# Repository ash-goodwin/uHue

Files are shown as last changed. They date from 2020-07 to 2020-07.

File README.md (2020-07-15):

# uHUE

*A USB-controlled LED light/indicator*

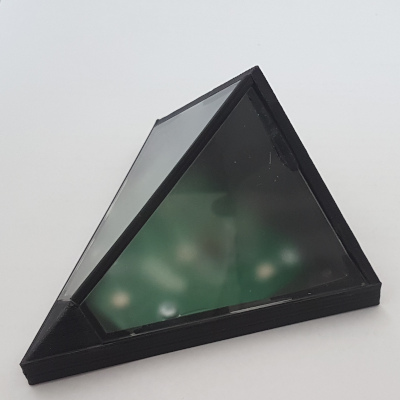
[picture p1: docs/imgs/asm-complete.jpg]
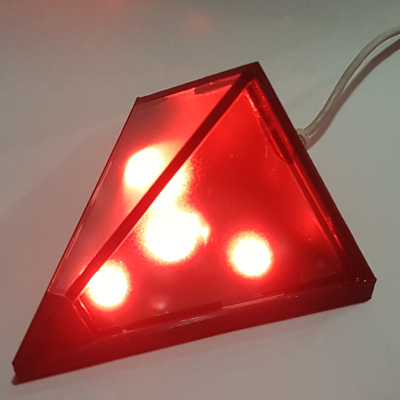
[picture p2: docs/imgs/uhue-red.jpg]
|  |  |
|--|--|

The uHUE is a simple USB-controlled light/indicator that arose from my need to add an externally visible status indicator to a PC-based test station I'd created. The idea was that it would allow the user to monitor the status of a test without having to be able to see the display. The uHUE interfaces with the PC using a USB-to-serial converter, whilst an on-board microcontroller controls the LEDs.

The colour shown by the uHUE is specified using three 8-bit values - one each for red, green and blue. Three 'patterns' are possible when showing a colour: solid, blink and fade. For blink and fade, the cycle time can also be controlled.

The housing is designed to allow the LED colour being shown to be viewed over a 180° horizontal arc and 90° vertical arc. For simplicity, I opted to use integrated magnets hold the uHUE in place rather than a more permanent fixing method.

For more information:
- [Circuit](docs/circuit.md)
- [Housing](docs/housing.md)
- [Protocol](docs/protocol.md)
- [Assembly](docs/assembly.md)

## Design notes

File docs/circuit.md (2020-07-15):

# Circuit

The uHUE uses four World Semi [WS2812B](datasheets/WS2812B.pdf) LEDs, controlled from a Microchip [PIC16F1704](datasheets/PIC16F1704.pdf). The PIC interfaces to the PC using a Silicon Labs [CP2104](datasheets/CP2104.pdf) USB-to-serial converter.

The WS2812B LEDs use a daisy-chained single-wire serial protocol to control the colour. It's a slightly odd protocol that uses different pulse widths to signify 1 and 0. Microchip have published an [application note](https://web.archive.org/web/20190417040127/http://ww1.microchip.com/downloads/en/AppNotes/00001606A.pdf) that explains how to use the Configurable Logic Cell (CLC) contained within some PICs to control the WS2812B. The app note is not written explicitly for the PIC16F1704 but is easily adapted.

I chose all components based on familiarity and the fact that I could have the PCBs assembled from in-stock items by JLCPCB. The only part I had to hand solder was the USB connector.

Below you can see the PCB as it came from JLCPCB, namely with all components except the USB connector.

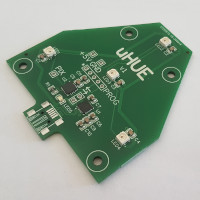
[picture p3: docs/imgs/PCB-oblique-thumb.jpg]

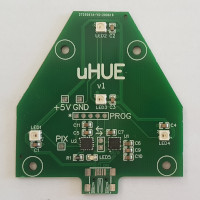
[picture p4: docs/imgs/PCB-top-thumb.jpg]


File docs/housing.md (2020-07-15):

# Housing

For my use case, the uHUE was going to be mounted to an overhead cable tray, with the LEDs projecting downwards. To allow the colour to be seen from side on, the housing uses two angled pieces of frosted acrylic to diffuse the light. This provides visibilty over a 180° horizontal arc and a 90° vertical arc. The frosted acrylic also makes the uHUE "glow" as a whole, rather than four point sources of light. The unit is held in place using three integrated magnets that are glued into the base, used to anchor the uHUE to a metal cable tray.

The housing is made of four parts, three of which can be 3D printed using FDM: the base, the frame and the spine. The fourth part is the laser-cut frosted acrylic "window". Two pieces of the acrylic are required per unit.

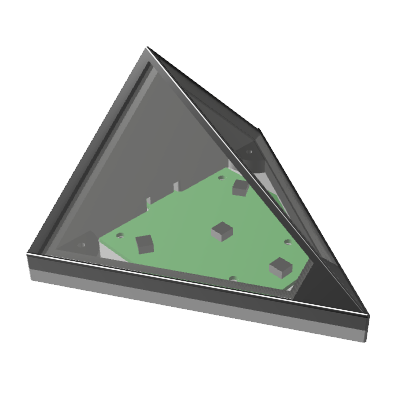
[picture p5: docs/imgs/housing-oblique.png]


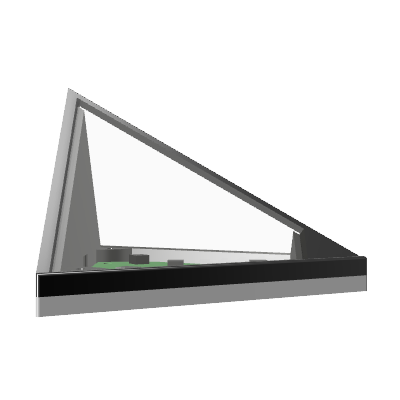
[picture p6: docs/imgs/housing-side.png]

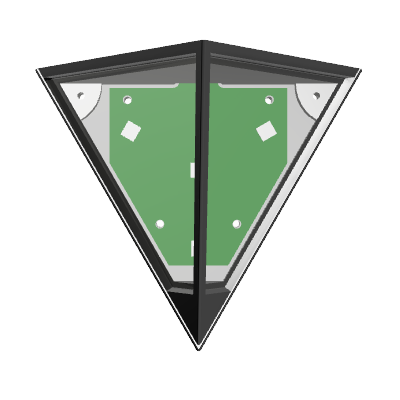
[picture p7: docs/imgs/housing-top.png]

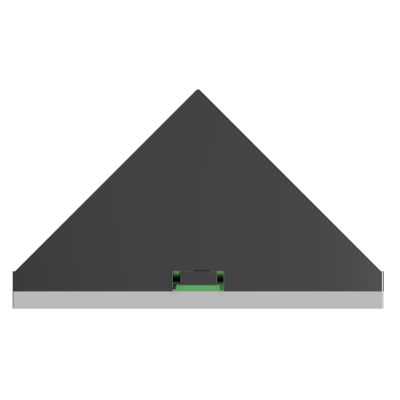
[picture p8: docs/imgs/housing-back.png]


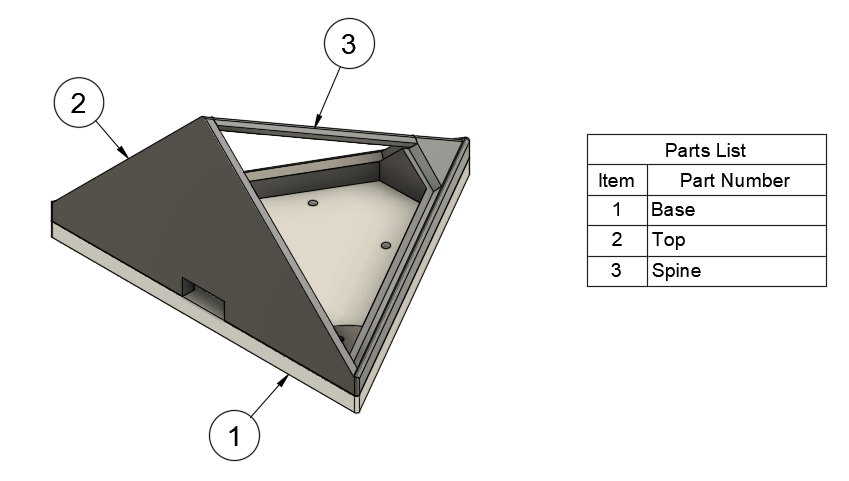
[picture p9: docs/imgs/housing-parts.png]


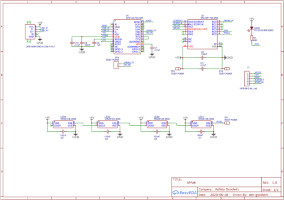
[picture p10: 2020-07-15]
docs/imgs/Schematic-thumb.jpg

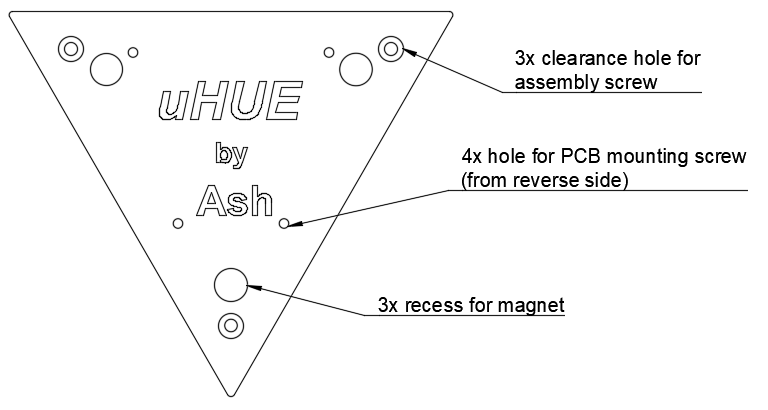
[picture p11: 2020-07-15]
docs/imgs/housing-base-detail.png

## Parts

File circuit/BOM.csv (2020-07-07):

ID | Name | Designator | Footprint | Quantity | Manufacturer Part | Manufacturer | Supplier | Supplier Part | LCSC Assembly
1 | 680 | R1 | R0805 | 1 | 0805W8F6800T5E | UniOhm | LCSC | C17798 | Yes
2 | 100nF | C9,C1,C2,C3,C4,C5 | C0805 | 6 | CC0805KRX7R9BB104 | YAGEO | LCSC | C49678 | Yes
3 | CP2104-F03-GM | U1 | QFN-24_L4.0-W4.0-P0.50-BL-EP2.8 | 1 | CP2104-F03-GM | SILICON LABS | LCSC | C47742 | Yes
4 | FC-2012HRK-620D | LED5 | LED0805-RD | 1 | FC-2012HRK-620D | NATIONSTAR | LCSC | C84256 | Yes
5 | WS2812B-3535 | LED4,LED3,LED1,LED2 | LED-SMD_4P-L3.5-W3.5-TL_WS2812B | 4 | WS2812B-3535 | Worldsemi | LCSC | C114583 | Yes
6 | TEST POINT | TP1,TP2,TP3 | HDR-M-2.54_1X1 | 3 |  |  | LCSC | C81276
7 | PIC16F1704-I/ML | U2 | QFN-16_L4.0-W4.0-P0.65-BL-EP2.6 | 1 | PIC16F1704-I/ML | MICROCHIP | LCSC | C145568 | Yes
8 | TEST POINT | TP4 | HDR-M-2.54_1X2 | 1 |  |  | LCSC | C124375
9 | HDR-M-2.54_1x5 | J1 | HDR-M-2.54_1X5 | 1
10 | 4.7uF | C7,C10,C11 | C0805 | 3 | CL21A475KAQNNNE | SAMSUNG | LCSC | C1779 | Yes
11 | USB-MINI-SMD-9.2X9.4-H3.7 | USB1 | MINI-USB-SMD_C105424 | 1 | USB-MINI-SMD-9.2X9.4-H3.7 | LCSC | LCSC | C105424
12 | 1uF | C6 | C0805 | 1 | CL21B105KBFNNNE | SAMSUNG | LCSC | C28323 | Yes

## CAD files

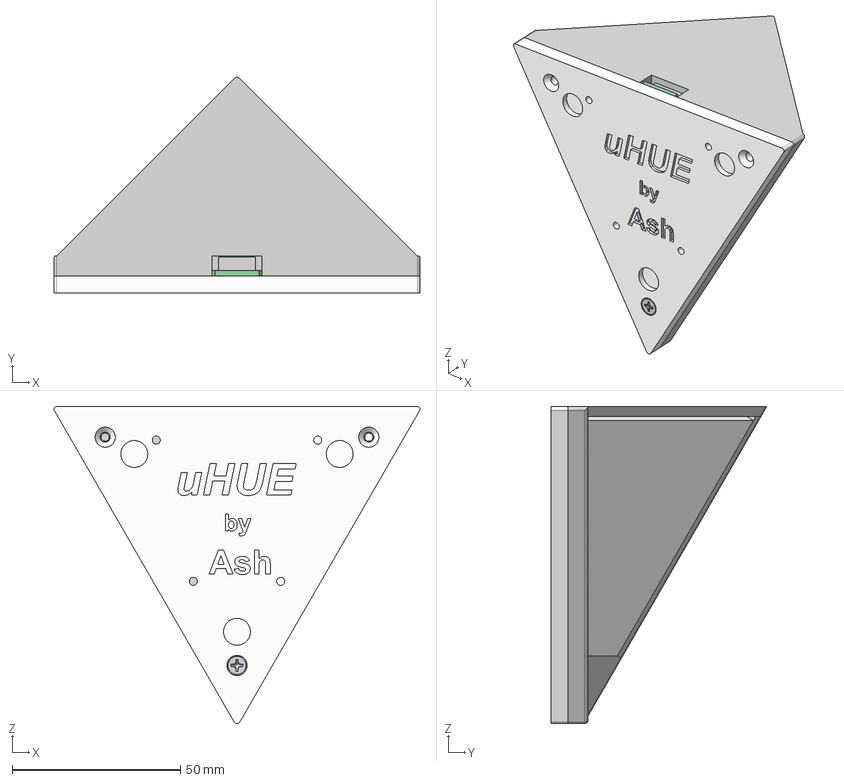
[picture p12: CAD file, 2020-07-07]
housing/assembly v10.iges
108.8 x 64.1 x 94.3 mm

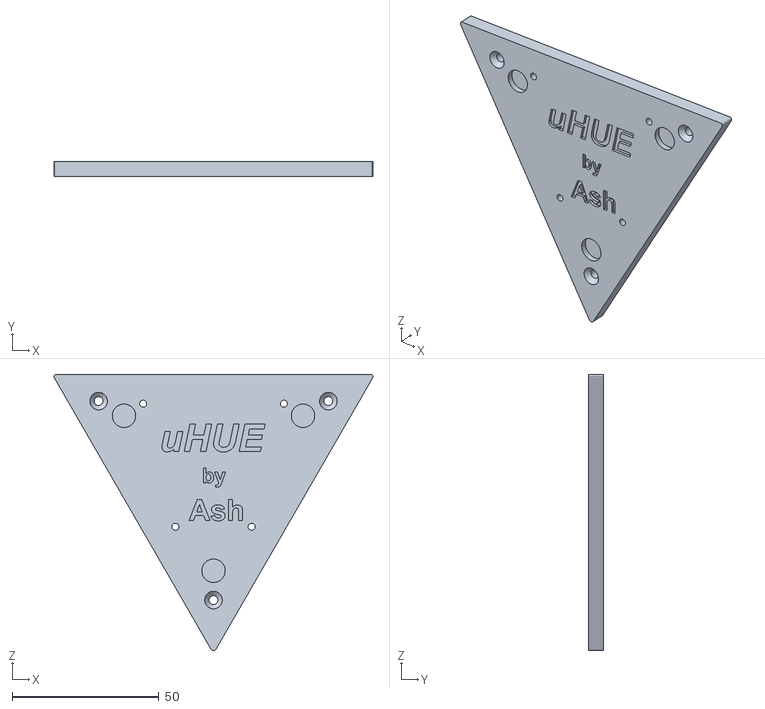
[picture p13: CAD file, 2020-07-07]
housing/Base.stl
108.8 x 5.00 x 94.3

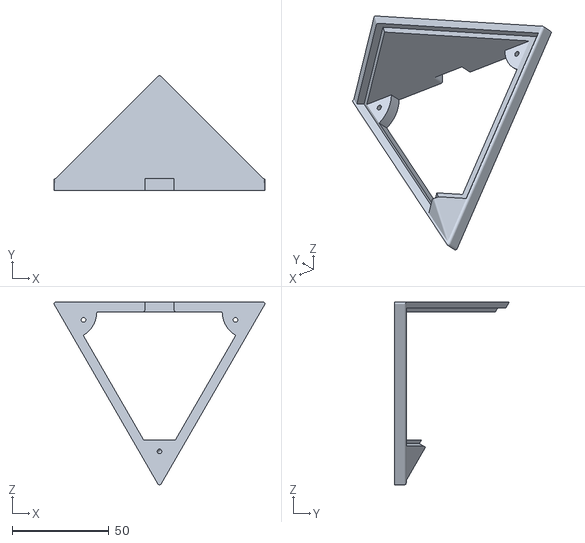
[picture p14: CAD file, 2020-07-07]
housing/Top.stl
108.8 x 59.1 x 94.3

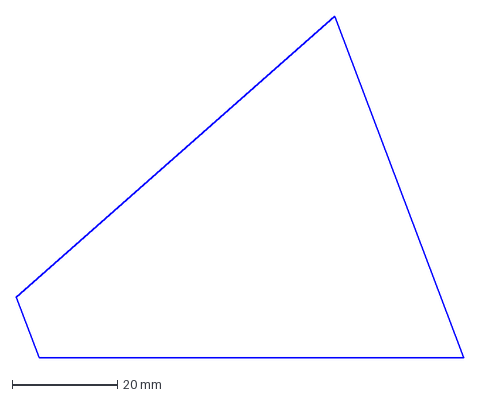
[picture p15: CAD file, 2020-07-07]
housing/pane.dxf
85.2 x 65.0 mm

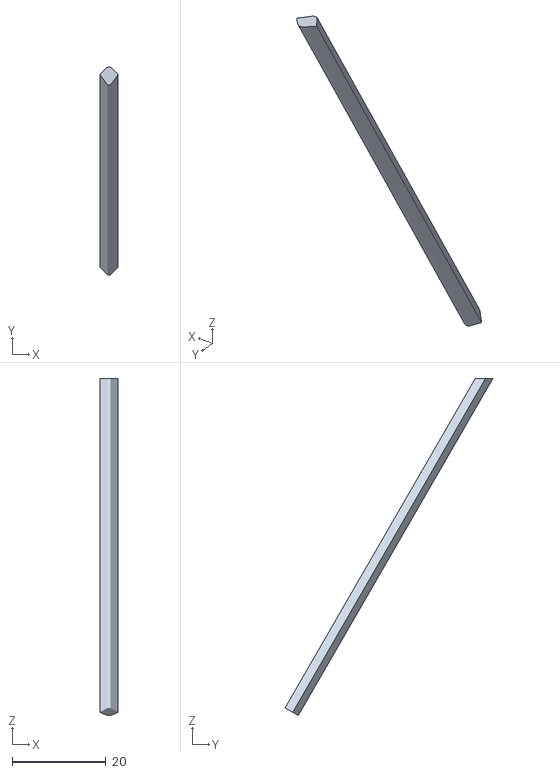
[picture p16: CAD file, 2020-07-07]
housing/Spine.stl
3.93 x 44.3 x 71.8

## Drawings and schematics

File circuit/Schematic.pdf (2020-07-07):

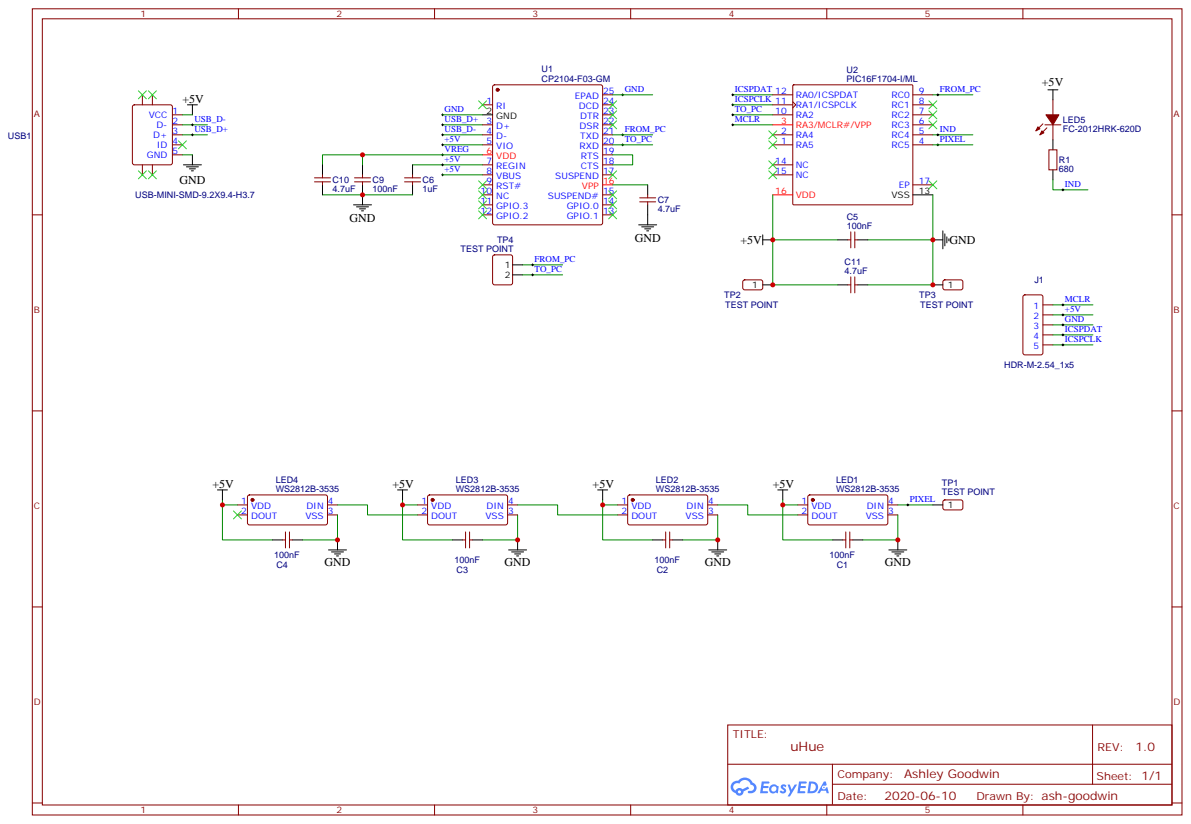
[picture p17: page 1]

Drawn By: ash-goodwin

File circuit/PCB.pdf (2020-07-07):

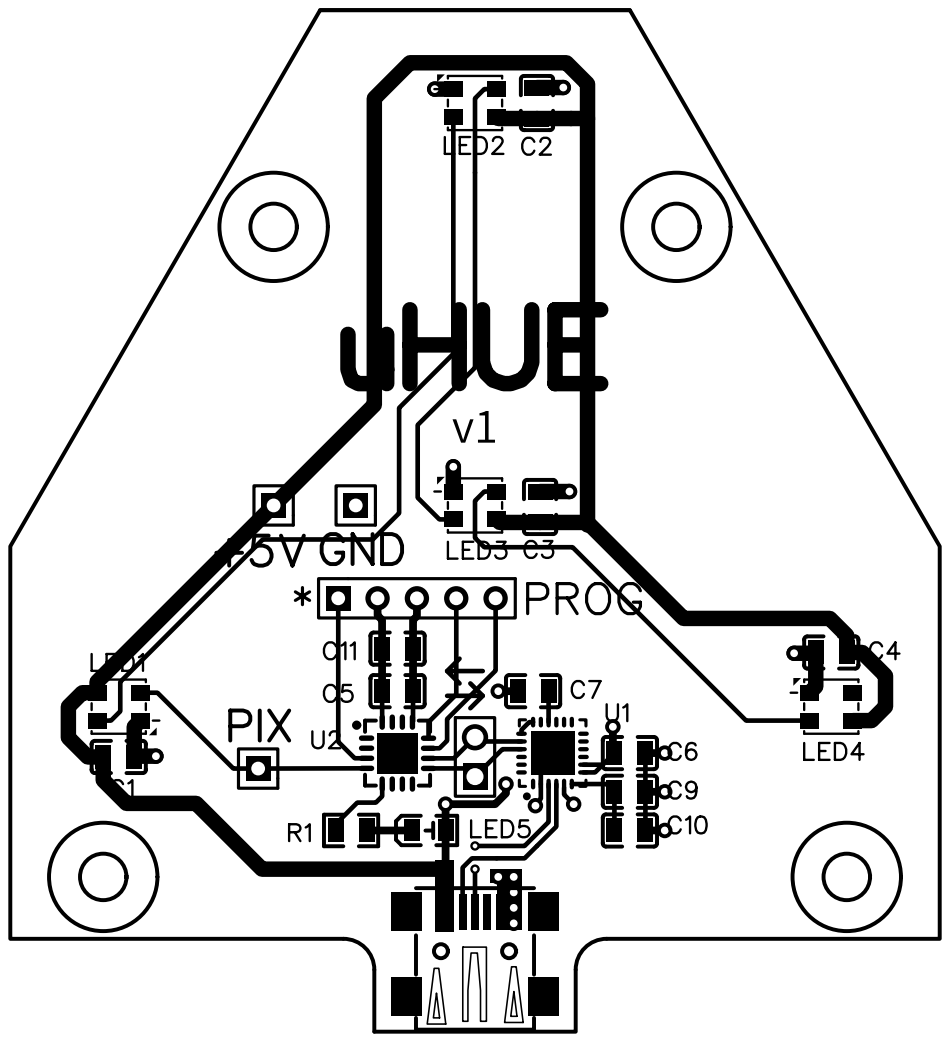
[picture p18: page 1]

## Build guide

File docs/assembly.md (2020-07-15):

# Assembly

Assembly of the uHUE is pretty straightforward.

Finishing the PCB:
1. Solder on the USB connector (if using JLCPCB SMT assembly service).
2. Program the PIC microcontroller. I have access to a 'REAL ICE' programmer, but any PIC-compatible programmer will work.
3. Test the uHUE using the [Tester software](../software) to make sure everything is working properly.

Assemble the housing:
1. Glue two pieces of the frosted acrylic into the 'frame' part.
2. Glue the 'spine' to the frame and acrylic panes, again with epoxy.
3. Separately, glue the three magnets into the base.

I used epoxy that I applied with a toothpick to glue everything together.

Once the glue/epoxy has cured:
1. Secure the PCB onto the base using 4x screws.
2. Secure the base to the frame with 3x screws.

| _Frame with 'windows' and spine glued into place_ |
|:--:|
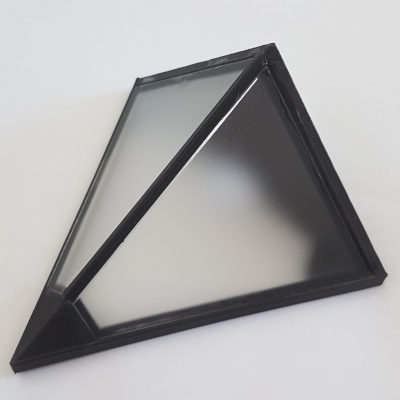
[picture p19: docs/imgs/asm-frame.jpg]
|  |

| _Base with magnet glued into place_ |
|:--:|
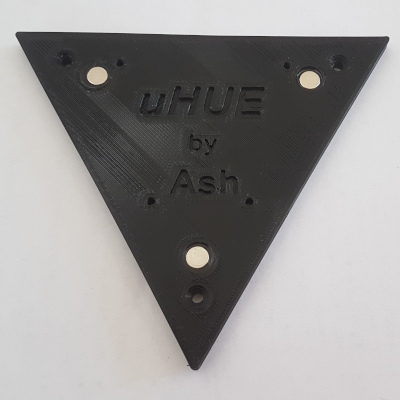
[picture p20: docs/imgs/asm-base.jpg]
|  |

| _PCB attached to base_ |
|:--:|
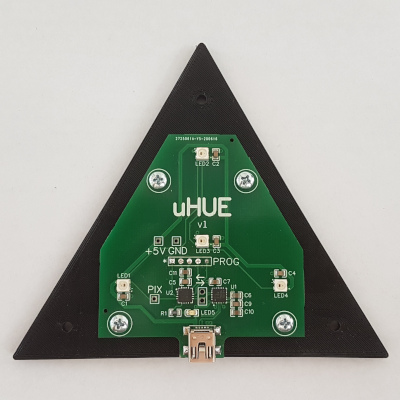
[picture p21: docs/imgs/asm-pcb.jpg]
|  |

| _Completed assembly_ |
|:--:|
|  |

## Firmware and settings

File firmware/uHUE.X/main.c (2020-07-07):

#include "main.h"
#include "led.h"
#include "mcc_generated_files/mcc.h"

#define FRAME_FLAG_START            0xFE
#define FRAME_FLAG_END              0xFF
#define FRAME_FLAG_ESCAPE           0xFD
#define FRAME_ESCAPE_XOR            0x20

#define ACTIVITY_LED_BLINK_COUNT    (10)

static struct {
    uint8_t buffer[10];
    int     count;
    
    uint8_t started : 1;
    uint8_t escapeNext : 1;
} receive;

static uint8_t activityLedCount = 0;

struct s_Timing timing;

void doReceive( void );
void processMessage( void );
void sendMessage( uint8_t *data, int length );
void blinkActivityLed( void );
void doActivityLed( void );

void main(void)
{
    // initialize the device
    SYSTEM_Initialize();

    Led_Initialise();
    
    // Lock PPS
    PPSLOCK = 0x55;
    PPSLOCK = 0xAA;
    PPSLOCKbits.PPSLOCKED = 1;
    
    // Enable the Global Interrupts
    INTERRUPT_GlobalInterruptEnable();

    // Enable the Peripheral Interrupts
    INTERRUPT_PeripheralInterruptEnable();

    while( true ) {
        doReceive();
        
        if( timing.tenMsTick ) {
            timing.tenMsTick = false;
            
            Led_Process();
            doActivityLed();
            
            CLRWDT();
        }
    }
}


void doReceive( void )
{
    while( EUSART_is_rx_ready() ) {
        uint8_t rx = EUSART_Read();
        
        blinkActivityLed();
                
        if( rx == FRAME_FLAG_START ) {
            receive.started = true;
            receive.count = 0;
            receive.escapeNext = false;
        }
        else if( rx == FRAME_FLAG_END ) {
            processMessage();
            receive.started = false;
        }
        else if( rx == FRAME_FLAG_ESCAPE ) {
            receive.escapeNext = true;
        }
        else if( receive.started ) {
            
            if( receive.count == sizeof( receive.buffer ) ){
                // Already filled buffer and next char wasn't the END flag.
                // :(
                receive.started = false;
                continue;
            }
            
            if( receive.escapeNext ) {
                rx ^= FRAME_ESCAPE_XOR;
                receive.escapeNext = false;
            }            
            
            receive.buffer[ receive.count++ ] = rx;            
        }
        
    }
}

void processMessage( void )
{
    uint8_t * data = receive.buffer;
    int dataLength = receive.count;
    struct s_LedColour colour = {
        .red = data[1],
        .green = data[2],
        .blue = data[3]
    };
    
    //sendMessage( data, dataLength );
    
    // Request for firmware version.
    // Format:  'v'
    if( dataLength == 1 && data[0] == 'v' ) {
        uint8_t version[] = "uHUE by Ash, v1";
        sendMessage( version, sizeof( version ) - 1 );
    }
    // Set solid colour.
    // Format:  'c', {red}, {green}, {blue}, {optional: cycle period, which is ignored}
    else if( dataLength >= 4 && data[0] == 'c' ) {
        Led_SetColour( PATTERN_SOLID, 0, colour );
    }
    // Set fading colour.
    // Format:  'f', {red}, {green}, {blue}, {cycle period in deci-seconds}
    else if( dataLength == 5 && data[0] == 'f' ) {
        Led_SetColour( PATTERN_FADE, data[4], colour );
    }
    // Set blinking colour.
    // Format:  'b', {red}, {green}, {blue}, {cycle period in deci-seconds}
    else if( dataLength == 5 && data[0] == 'b' ) {
        Led_SetColour( PATTERN_BLINK, data[4], colour );
    }    
}

void sendMessage( uint8_t *data, int length )
{
    EUSART_Write( FRAME_FLAG_START );
    
    while( length-- ) {
        if( *data >= FRAME_FLAG_ESCAPE ) {
            EUSART_Write( FRAME_FLAG_ESCAPE );
            EUSART_Write( *data ^ FRAME_ESCAPE_XOR );
        }
        else {
            EUSART_Write( *data );
        }
        data++;
    }
    
    EUSART_Write( FRAME_FLAG_END );
}

void blinkActivityLed( void )
{
    activityLedCount = ACTIVITY_LED_BLINK_COUNT;
    IO_LED_SetLow();    
}

void doActivityLed( void )
{
    if( activityLedCount ) {
        if( --activityLedCount == 0 ) {
            IO_LED_SetHigh();
        }
    }
}

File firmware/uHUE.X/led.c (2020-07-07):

#include "main.h"
#include "led.h"
#include "mcc_generated_files/mcc.h"

#define TICKS_PER_DECISECOND        (TICKS_PER_SECOND / 10)
#define NUM_LEDS                    (4)


static struct {
    struct {
        enum e_LedPattern   pattern;
        uint16_t            patternTime;
        struct s_LedColour  colour;
    } Setting;
        
    uint16_t                 cycleTimer;    
} led;

static const struct s_LedColour ColourOff = { 0, 0, 0 };

static void _WriteColour( struct s_LedColour colour );
static struct s_LedColour _MixColours( struct s_LedColour colourA, struct s_LedColour colourB, uint16_t dividend, uint16_t divisor );



void Led_Initialise( void )
{
    SPI_Open( SPI_DEFAULT );
    _WriteColour( ColourOff );
}
        
void Led_SetColour( enum e_LedPattern pattern, uint8_t patternTime, struct s_LedColour colour )
{
    led.Setting.pattern = pattern;
    led.Setting.patternTime = (uint16_t)patternTime * TICKS_PER_DECISECOND;
    led.Setting.colour = colour;    
    
    // Reset fade/blink timer
    led.cycleTimer = 0;
    
    switch( led.Setting.pattern ){
        case PATTERN_SOLID:
            // Just set the colour and done!
            _WriteColour( led.Setting.colour );
            break;

        case PATTERN_FADE:
            // Start with light off.
            _WriteColour( ColourOff );
            break;

        case PATTERN_BLINK:
            // Start with selected colour.
            _WriteColour( led.Setting.colour );
            break;
    } 
}


void Led_Process( void )
{       
    // Increase cycle timer.
    led.cycleTimer += 1;
    if( led.cycleTimer >= led.Setting.patternTime ) {
        led.cycleTimer = 0;
    }
    
    // Update light with new colour based on new position in cycle.v
    switch( led.Setting.pattern ){
        case PATTERN_SOLID:
            // Do nothing, colour doesn't change over time.
            break;

        case PATTERN_FADE: {
            // At time 0, the colour is 'off'.
            // Up to time (period / 2), the colour slowly becomes 'setting'.
            // Up to time (period), the colour slowly becomes 'off'.
            uint16_t halfPeriod = led.Setting.patternTime / 2;
            if( led.cycleTimer < halfPeriod ) {
                _WriteColour( _MixColours( ColourOff, led.Setting.colour, led.cycleTimer, halfPeriod ) );
            }
            else {
                uint16_t timeInSecondHalf = led.cycleTimer - halfPeriod;
                _WriteColour( _MixColours( led.Setting.colour, ColourOff, timeInSecondHalf, halfPeriod ) );
            }
            break;
        }

        case PATTERN_BLINK:
            // Whilst time < (period / 2), the colour is 'setting'.
            // For (period / 2) < time < period, the colour is 'off'.
            
            if( led.cycleTimer == 0 ) {
                _WriteColour( led.Setting.colour );
            }
            else if( led.cycleTimer == (led.Setting.patternTime / 2) ) {
                _WriteColour( ColourOff );
            }
            break;
    } 
}

static void _WriteColour( struct s_LedColour colour )
{
    int numLeds = NUM_LEDS;
    while( numLeds-- ) {
        (void) SPI_ExchangeByte( colour.green );
        (void) SPI_ExchangeByte( colour.red );
        (void) SPI_ExchangeByte( colour.blue );
    }
}

static uint8_t _Mix( uint8_t valueA, uint8_t valueB, uint16_t dividend, uint16_t divisor )
{
    if( dividend == 0 ) {
        return valueA;
    }
    else if( dividend >= divisor ) {
        return valueB;
    }
    
    uint8_t t = (((uint32_t) valueB) * dividend) / divisor;
    
    dividend = divisor - dividend;
    uint8_t u = (((uint32_t) valueA) * dividend) / divisor;
    
    return t + u;
}

static struct s_LedColour _MixColours( struct s_LedColour colourA, struct s_LedColour colourB, uint16_t dividend, uint16_t divisor )
{
    struct s_LedColour res = {
        .red = _Mix( colourA.red, colourB.red, dividend, divisor ),
        .green = _Mix( colourA.green, colourB.green, dividend, divisor ),
        .blue = _Mix( colourA.blue, colourB.blue, dividend, divisor ),
    };
    
    return res;
}
